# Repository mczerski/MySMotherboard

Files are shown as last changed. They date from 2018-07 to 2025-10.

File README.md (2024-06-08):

# MySMotherboard
## Motherboard for MySensors nodes

This is a motherboard for creating MySensors nodes based on the atmega328p MCU. It is meant to be combined with a MySX daughter board to create fully functional MySensors node. It is primarly for battery powered nodes but can be also used as a gateway or ac powered node (ac power supply is not part of this project). It features multiple powering options and supports RS485 or RFM69 RF communication options. The size of the board is just a little bigger than a cr123a battery holder.

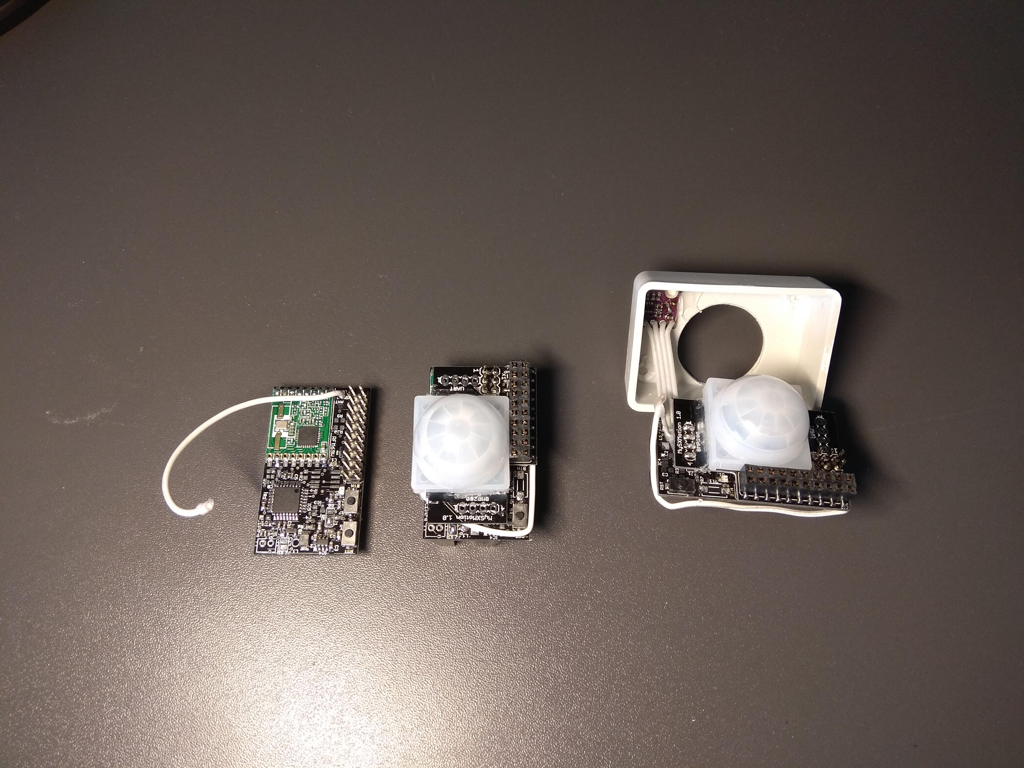
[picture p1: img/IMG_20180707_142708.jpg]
MySMotherBoard top

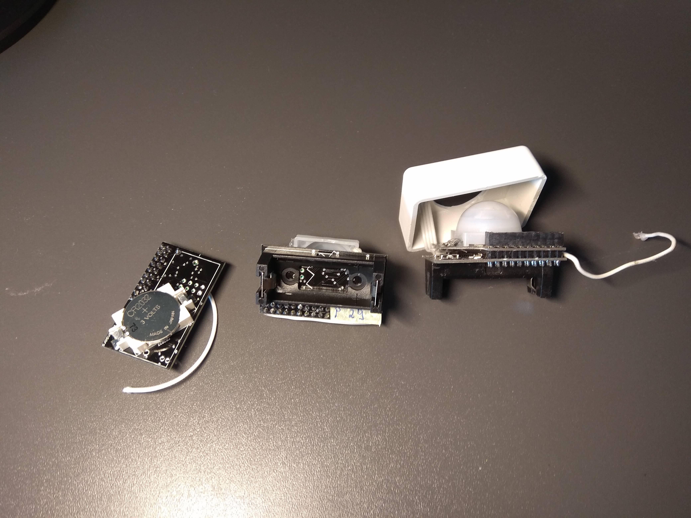
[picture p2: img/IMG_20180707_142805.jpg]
MySMotherBoard bottom


## Features:

1. atmega328p MCU
2. Multiple power source options:
  * CR123A battery or 16340 rechargable li-ion battery
  * CR2032 battery
  * JST-PH2 connector for rechargable li-ion battery
  * 24V on the 2.54mm screw terminal
  * VRAW from MySX connector
3. Multiple voltage regulator options:
  * MCP1640C boost converter with bypass option
  * TPS782 LDO linear regulator
  * AP63205WU buck converter
  * no voltage regulation - direct voltage from battery
4. Input voltage reverse polarity protection
5. Overvoltage protection for RS485 data lines
6. Battery voltage divider to monitor battery voltage
7. ATSHA204A supported
8. AT25DF512C flash suppoerted
9. RFM69 RF SMD module
10. RF module interrupt D2 pin can be disconnected if not used
11. SP3485 for RS485 communication
12. reset button
13. user button
14. user led
15. external oscillator for atmega

## HOW TO

### Minimum required parts to solder are:

1. MCU related parts:
C5, C6, C7, C10, IC5, R7
2. Radio module related parts:
C1, R1, RFM69W, antenna to ANT pad and R12 (R12 is just a 0Ohm jumper required to connect RFM69 interrupt with D2 pin)
3. RS485 interface related parts:
U8
3. MySX connector:
X2

This is bare minimum that is required to start with this board. In this configuration the board can be powered from the MySX connector VCC pin with voltage between 1.9V - 3.6V.

### Optional parts to solder are:

1. MCU related parts:
 * for user led - R8, D1
 * for reset button - RST
 * for user button connected to D2 pin - BTN
 * for I2C pull-up resistors - R9, R10
 * for external oscillator - C8, C9, Q2
2. External flash related parts:
R2, IC2
WARNING: flash chips consumes a lot of uA of current so it is not suited for battery powered nodes.
3. ATSHA204A related parts:
IC3
ATSHA204A requires at least 2.0V power supply
4. RS485 related parst (overvoltage protection on data pins):
F1, F2, D2, D3

### Powering options

The powering option is choosed in two steps. First is to select the voltage source, and second is to choose the voltage conversion type. Between the voltage source and the voltage converter ther is the reverse polarity protection mosfet Q1 which is required for all options and voltage divider for battery voltage monitoring which is not required.

Voltage source options are:
1. CR123A battery or 16340 rechargable li-ion battery. To select this option just solder CR123A battery holder.
2. CR2032 battery. To chosse this option just solder CR2032 battery holder.
3. JST-PH2 connector. To choose this option just solder the X1 connector.
4. 24V input on 2.54mm screw terminal
5. VRAW from MySX connector. To choose this option the J2 jumper must be shorted.

Reverse polarity battery protection:
Q1

Voltage divider for battery voltage monitoring:
R5, R6, C4

Voltage convertion options are:
1. MCP1640C boost converter
R3, R4, R11, C2, C3, L1, IC4, J1 jumper should connect VBOOST with VCC.
The MCP1640C boost converter can be put into bypass mode so it just passes the input voltage. It is controller by the A2 pin and the bypass mode is the default. The purpose of this functionality is to be able to run the MCU directly from the battery and to boost the voltage only for the moment required to make measurements with sensors that require higher voltages.
2. TPS782 LDO linear regulator
C13, C14, IC1. J1 jumper should connect VREG with VCC. The C12 should be replaced by the 0Ohm resistor. The C12 capacitor was designed for the APE8865 LDo which consumes much more current that TPS782.
3. AP63205WU buck converter
C1, C6, C11, U7, Q2 (for high voltage reverse polarity protection)
4. No voltage regulation
There is actually no direct way to shoose this option, but it can be done by shorting pins number 5 and 6 of the IC4 and J1 jumper should connect VBOOST with VCC.

### Powering examples.

1. Very low power temperature and humidity sensor based on the BME280 sensor.
This node uses the "No voltage conversion" option because the BME280 sensor can work with voltages as low as 1.2V. So the node may be powered just by 3V coin-cell battery. This type of node uses just CR2032 battery holder.

2. Very low power node with DS18B20 temperature sensors that require minimum 3V power supply.
This type of node uses MCP1640C boost converter to boost battery voltage for the measurement period. Use CR2032 battery holder and MCP1640C boost converter option. In the software controll properly the A2 pin to turn on/off boost conversion.

3. Motion sensor node.
Motion sensor such as AS312 consumes quite a lot of power and needs voltage between 2.7V and 3.3V. Powering it directly with 3V battery is not good, so we could use the boost converter. But boost converter makes to much noise for AS312 to work properly. The AS312 works the best with 3V LDO, so the power source should have higher voltage. The best options is to use 3.7V 16340 rechargable li-ion battery which fits into CR123A battery holder. Use TPS782 LDO option to power the MCU and RF module and short the J2 jumper to power the VRAW pin directly with 3.7V battery. Then the motion sensor daugher board should power the AS312 sensor with another LDO from the VRAW pin.

4. RS485 node.
RS485 node uses 24V input on the 2.54mm screw terminal which delivers power and RS485 communication to the board. It also utilises high voltage reverse polarity protection and overvoltage protection for data pins so any wiring mistakes will not cause damage to the board. Onboard AP63205WU buck converter provides 5V input voltage for the board which can be used directly or can be fed to the 3V LDO regulator. By soldering JP1 jumper 5V power can be connected to VRAW on the MySX connector.

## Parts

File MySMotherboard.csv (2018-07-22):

Part | Value | Package | Description
BTN |  |  | microswitch (e.g. KSR251GLFS https://www.ckswitches.com/media/1466/ksr.pdf)
RST |  |  | microswitch (e.g. KSR251GLFS https://www.ckswitches.com/media/1466/ksr.pdf)
X1 |  |  | JST-PH2 connector (http://www.jst-mfg.com/product/pdf/eng/ePH.pdf)
X2 |  |  | 10X02 PIN HEADER
C1 | 10u | C0603 | Capacitor
C2 | 4.7u | C0603 | Capacitor
C3 | 10u | C0603 | Capacitor
C4 | 100n | C0402 | Capacitor
C5 | 100n | C0402 | Capacitor
C6 | 100n | C0402 | Capacitor
C7 | 100n | C0402 | Capacitor
C8 | 22p | C0402 | Capacitor
C9 | 22p | C0402 | Capacitor
C10 | 100n | C0402 | Capacitor
C12 | 10n | C0402 | Capacitor
C13 | 10u | C0603 | Capacitor
C14 | 10u | C0603 | Capacitor
CR123A |  |  | CR123A battery holder (https://www.challengeelectronics.com/downloads/battery_accessories/lithium/BHC-CR123A.pdf)
CR2032 |  |  | CR2032 battery holder (https://www.tme.eu/pl/Document/add8937505ee3ddd8664e6e70d6b380d/DS1092-10-W6L.pdf)
D1 |  | CHIP-LED0805 | LED
IC1 | APE8865Y5-30-HF-3 | SOT25 | 150mA Low Noise LDO Voltage Regulator with Enable
IC2 | AT25DF512C-SSHN-B | SO-08 | Serial EEPROM 4K/ 8K , SPI bus
IC3 | ATSHA204A | SOT23 | CryptoAuthentication IC
IC4 | MCP1640CT-I/CHY | SOT95 | Synchronous Boost Regulator
IC5 | ATMEGA328P-AU | TQFP32 | MCU
L1 | 4.7u | L3225P | INDUCTOR, European symbol
NRF24L01 | WIRELESS-NRF24L01 |  | 2.4 GHz Wireless Module based on NRF24L01 chip
RFM69W | RFM69HW |  | RFM69W module
Q1 |  | SOT-23 | MOS FET
Q2 |  |  | 8MHz crystal oscillator
R1 | 1M | R0603 | Resistor
R2 | 1M | R0603 | Resistor
R3 | 1M | R0603 | Resistor
R4 | 620k | R0603 | Resistor
R5 | 1M | R0603 | Resistor
R6 | 100k | R0603 | Resistor
R7 | 1M | R0603 | Resistor
R8 | 1k | R0603 | Resistor
R9 | 10k | R0603 | Resistor
R10 | 10k | R0603 | Resistor
R11 | 1M | R0603 | Resistor
R12 | 0 | R0603 | Resistor

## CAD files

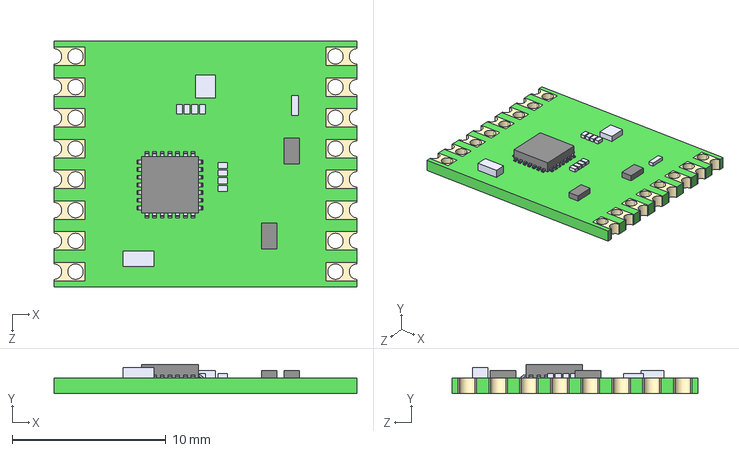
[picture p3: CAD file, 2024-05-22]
3dshapes/RFM69HW-868S2--3DModel-STEP-1.STEP
19.7 x 1.90 x 16.0 mm

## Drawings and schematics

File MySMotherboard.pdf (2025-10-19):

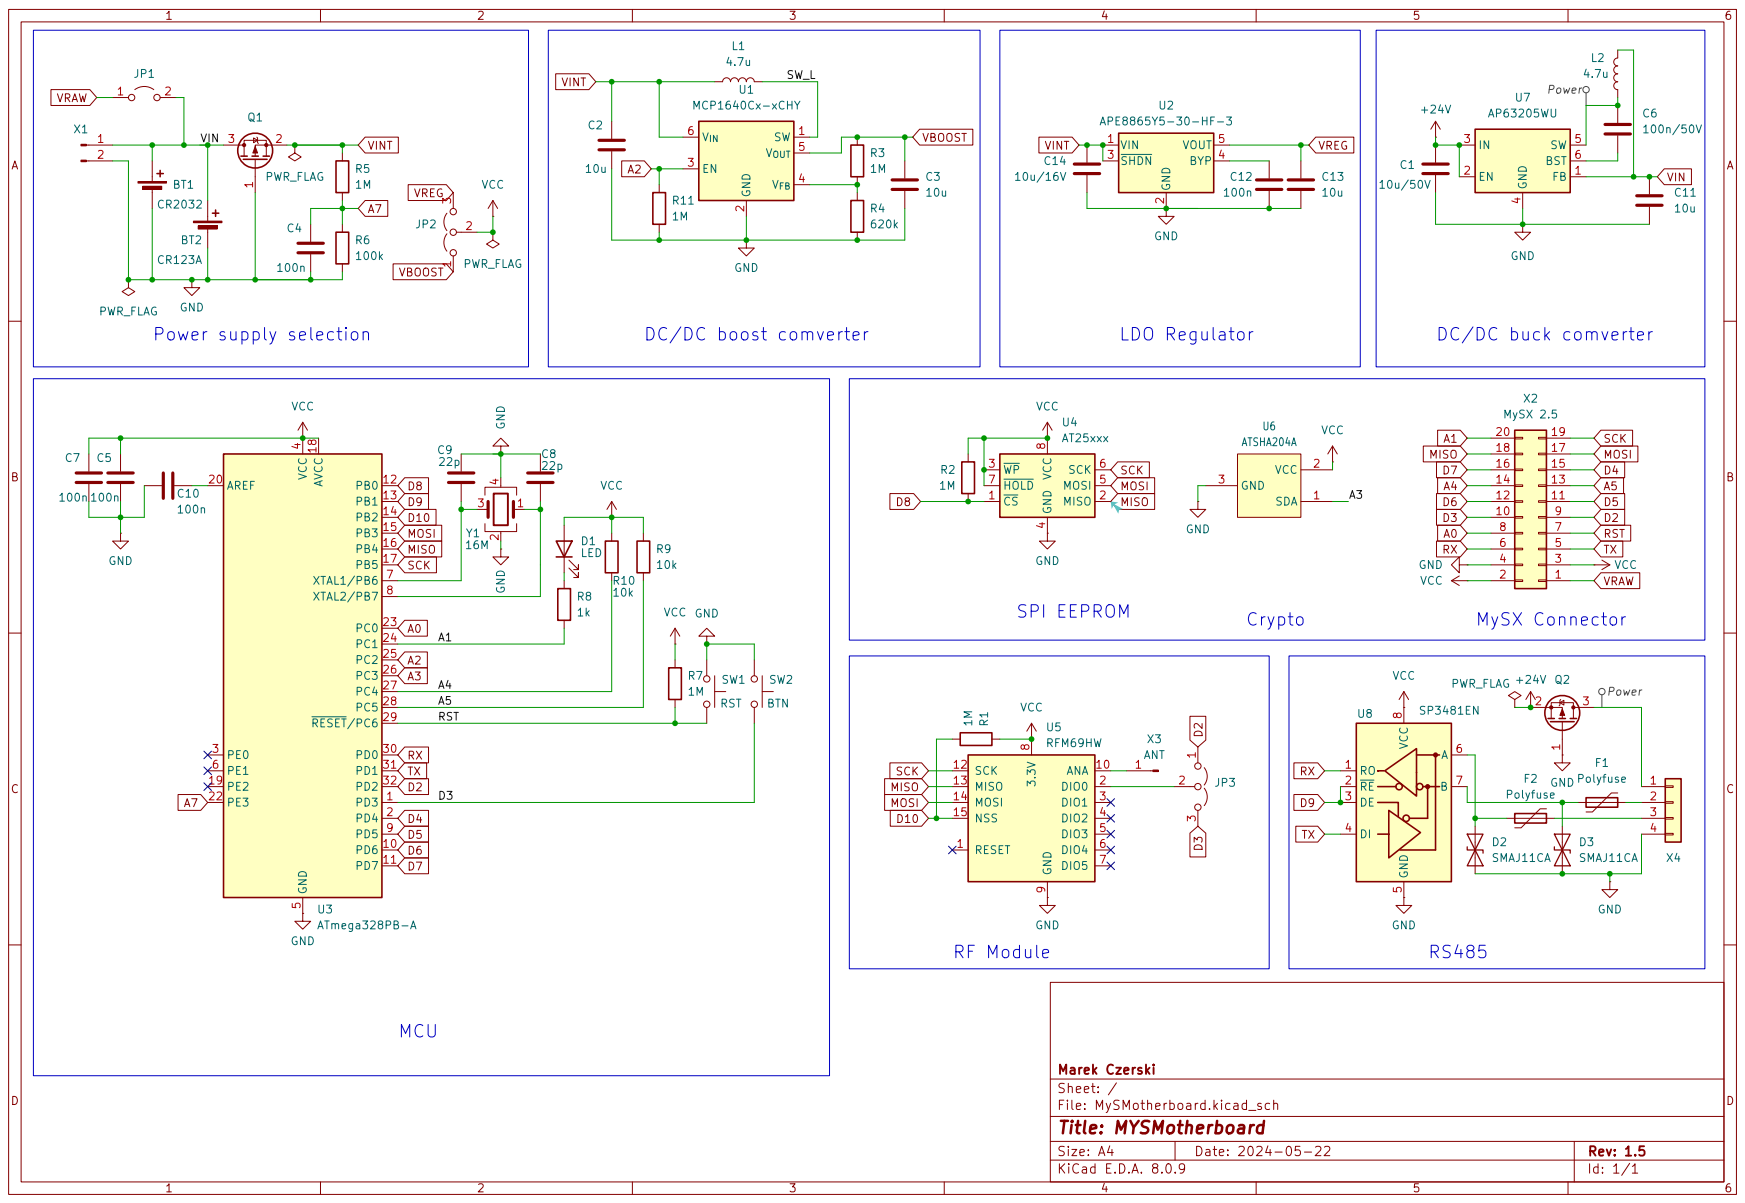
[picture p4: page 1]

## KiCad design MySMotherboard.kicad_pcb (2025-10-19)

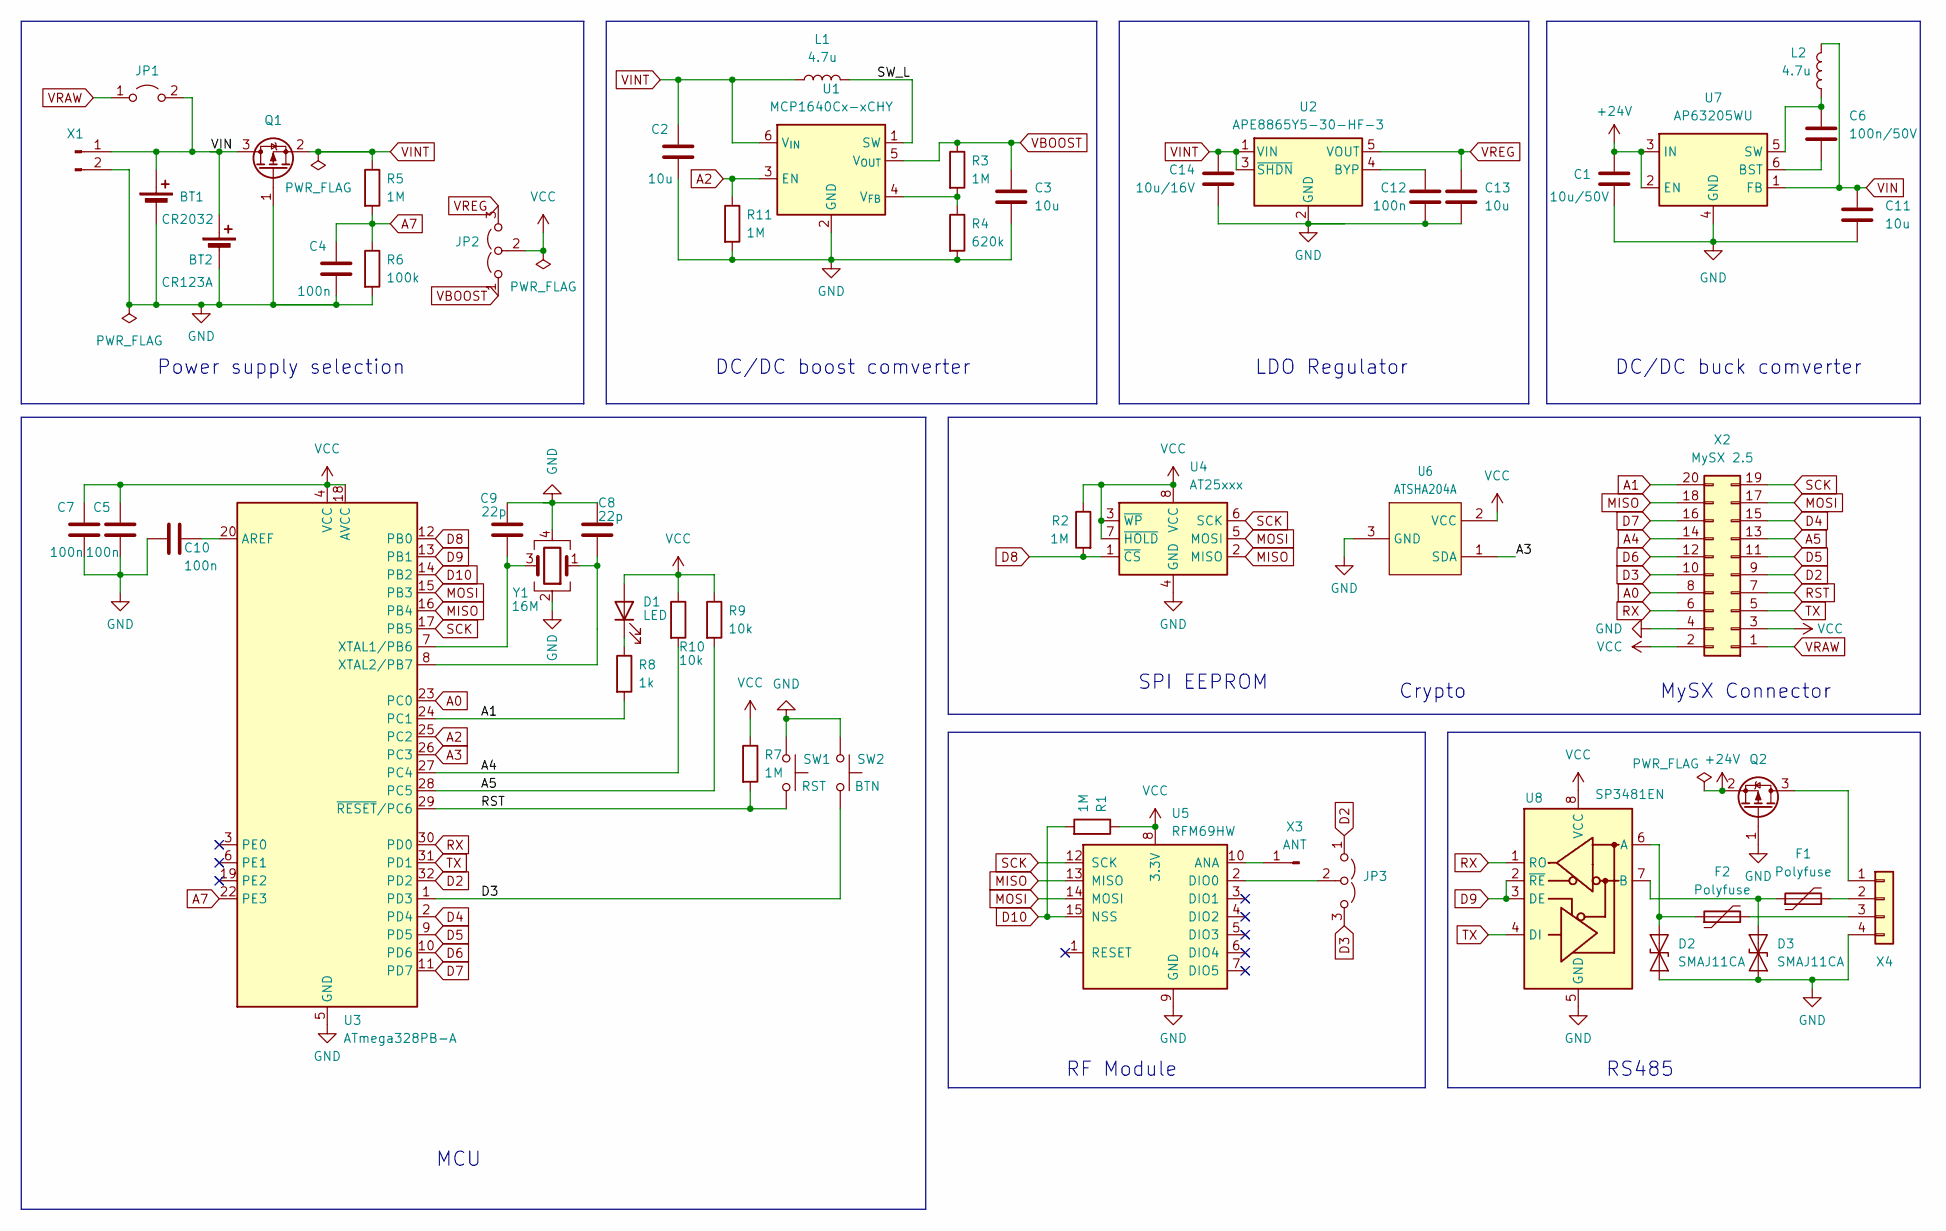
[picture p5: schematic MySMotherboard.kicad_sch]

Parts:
BT1: CR2032; BatteryHolder_Keystone_1060_1x2032
BT2: CR123A; BH123A
C1: 10u/50V; C_1206_3216Metric
C2, C3, C13: 10u; C_0603_1608Metric
C4, C5, C7, C10, C12: 100n; C_0402_1005Metric
C6: 100n/50V; C_0402_1005Metric_Pad0.74x0.62mm_HandSolder
C8, C9: 22p; C_0402_1005Metric
C11: 10u; C_1206_3216Metric
C14: 10u/16V; C_0603_1608Metric
D1: LED; LED_0805_2012Metric_Pad1.15x1.40mm_HandSolder
D2, D3: SMAJ11CA; D_SMA
F1, F2: Polyfuse; Fuse_1206_3216Metric_Pad1.42x1.75mm_HandSolder
JP1: SolderJumper-2_P1.3mm_Open_RoundedPad1.0x1.5mm
JP2, JP3: SolderJumper-3_P1.3mm_Open_RoundedPad1.0x1.5mm
L1: 4.7u; L_1210_3225Metric_Pad1.42x2.65mm_HandSolder
L2: 4.7u; L_1210_3225Metric
Q1, Q2: SOT-23
R1, R2, R3, R5, R7, R11: 1M; R_0603_1608Metric
R4: 620k; R_0603_1608Metric
R6: 100k; R_0603_1608Metric
R8: 1k; R_0603_1608Metric
R9, R10: 10k; R_0603_1608Metric
SW1: RST; SW_SPST_EVQPE1
SW2: BTN; SW_SPST_EVQPE1
U1: MCP1640Cx-xCHY; SOT-23-6
U2: APE8865Y5-30-HF-3; SOT-23-5
U3: ATmega328PB-A; TQFP-32_7x7mm_P0.8mm
U4: AT25xxx; SOIC-8_3.9x4.9mm_P1.27mm
U5: RFM69HW; HOPERF_RFM69HW
U6: ATSHA204A; SOT-23
U7: AP63205WU; TSOT-23-6
U8: SP3481EN; SOIC-8_3.9x4.9mm_P1.27mm
X1: JST_PH_B2B-PH-K_1x02_P2.00mm_Vertical
X2: MySX 2.5; PinHeader_2x10_P2.54mm_Vertical
X3: ANT; PinHeader_1x01_P2.54mm_Vertical
X4: TerminalBlock_Phoenix_MPT-0,5-4-2.54_1x04_P2.54mm_Horizontal
Y1: 16M; Crystal_SMD_2520-4Pin_2.5x2.0mm

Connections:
+24V: C1.1, Q2.2 (S), U7.2 (EN), U7.3 (IN)
/SW_L: L1.2, U1.1 (SW)
A0: U3.23 (PC0), X2.8
A1: R8.2, U3.24 (PC1), X2.20
A2: R11.1, U1.3 (EN), U3.25 (PC2)
A3: U3.26 (PC3), U6.1 (SDA)
A4: R10.2, U3.27 (PC4), X2.14
A5: R9.2, U3.28 (PC5), X2.13
A7: C4.1, R5.2, R6.1, U3.22 (PE3)
D2: JP3.1 (A), U3.32 (PD2), X2.9
D3: JP3.3 (B), SW2.1, U3.1 (PD3), X2.10
D4: U3.2 (PD4), X2.15
D5: U3.9 (PD5), X2.11
D6: U3.10 (PD6), X2.12
D7: U3.11 (PD7), X2.16
D8: R2.2, U3.12 (PB0), U4.1 (~CS)
D9: U3.13 (PB1), U8.2 (~RE), U8.3 (DE)
D10: R1.2, U3.14 (PB2), U5.15 (NSS)
GND: BT1.2 (-), BT2.2 (-), C1.2, C2.2, C3.2, C4.2, C5.2, C7.2, C8.1, C9.2, C10.2, C11.2, C12.2, C13.2, C14.2, D2.1 (A1), D3.1 (A1), Q1.1 (G), Q2.1 (G), R4.2, R6.2, R11.2, SW1.2, SW2.2, U1.2 (GND), U2.2 (GND), U3.5 (GND), U3.21 (GND), U4.4 (GND), U5.9 (GND), U5.11 (GND), U6.3 (GND), U7.4 (GND), U8.5 (GND), X1.2, X2.4, X4.4, Y1.2, Y1.4
MISO: U3.16 (PB4), U4.2 (MISO), U5.13 (MISO), X2.18
MOSI: U3.15 (PB3), U4.5 (MOSI), U5.14 (MOSI), X2.17
unnamed: D1.1 (K), R8.1
unnamed: D2.2 (A2), F2.1, U8.6 (A)
unnamed: D3.2 (A2), F1.1, U8.7 (B)
unnamed: JP3.2 (C), U5.2 (DIO0)
unnamed: Q2.3 (D), X4.1
unnamed: R3.2, R4.1, U1.4 (V_{FB})
unnamed: C12.1, U2.4 (BYP)
unnamed: C10.1, U3.20 (AREF)
unnamed: C9.1, U3.7 (XTAL1/PB6), Y1.3
unnamed: C8.2, U3.8 (XTAL2/PB7), Y1.1
unnamed: U5.10 (ANA), X3.1
unnamed: C6.1, U7.6 (BST)
unnamed: C6.2, L2.1, U7.5 (SW)
unnamed: F1.2, X4.2
unnamed: F2.2, X4.3
RST: R7.2, SW1.1, U3.29 (~RESET/PC6), X2.7
RX: U3.30 (PD0), U8.1 (RO), X2.6
SCK: U3.17 (PB5), U4.6 (SCK), U5.12 (SCK), X2.19
TX: U3.31 (PD1), U8.4 (DI), X2.5
VBOOST: C3.1, JP2.1 (A), R3.1, U1.5 (V_{OUT})
VCC: C5.1, C7.1, D1.2 (A), JP2.2 (C), R1.1, R2.1, R7.1, R9.1, R10.1, U3.4 (VCC), U3.18 (AVCC), U4.3 (~WP), U4.7 (~HOLD), U4.8 (VCC), U5.8 (3.3V), U6.2 (VCC), U8.8 (VCC), X2.2, X2.3
VIN: BT1.1 (+), BT2.1 (+), C11.1, JP1.2 (B), L2.2, Q1.3 (D), U7.1 (FB), X1.1
VINT: C2.1, C14.1, L1.1, Q1.2 (S), R5.1, U1.6 (V_{IN}), U2.1 (VIN), U2.3 (~SHDN)
VRAW: JP1.1 (A), X2.1
VREG: C13.1, JP2.3 (B), U2.5 (VOUT)

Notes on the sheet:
RS485
LDO Regulator
DC/DC boost comverter
RF Module
Crypto
MySX Connector
MCU
SPI EEPROM
DC/DC buck comverter
Power supply selection

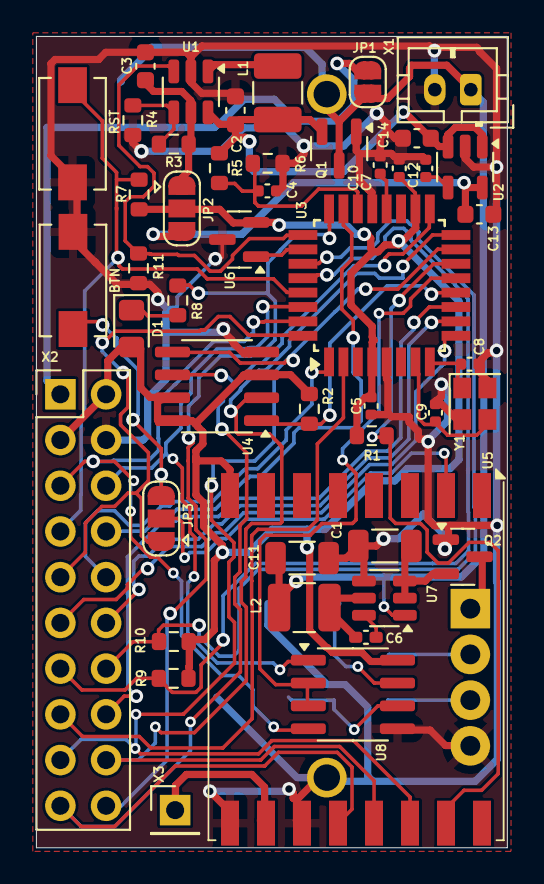
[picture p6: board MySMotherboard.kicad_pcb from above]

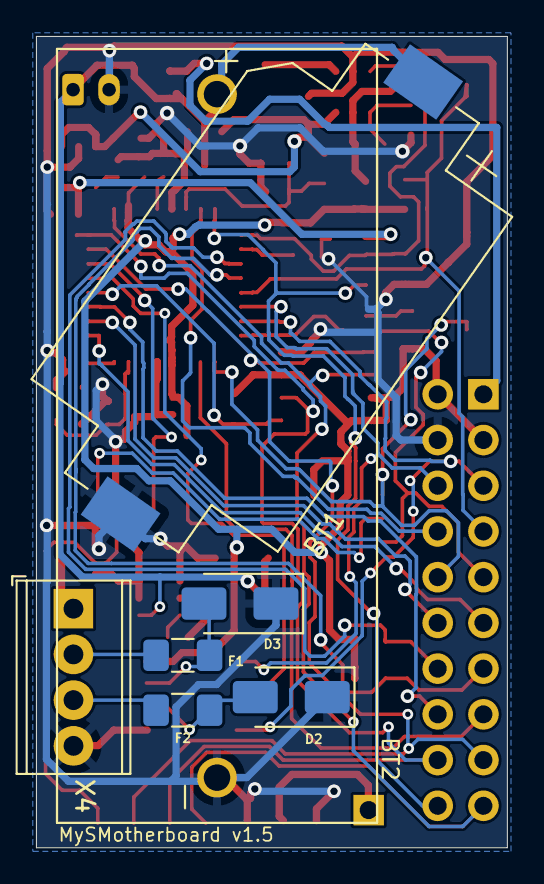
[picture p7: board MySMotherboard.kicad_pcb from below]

Board: 2 copper layers, 26.2 x 45.1 mm, 54 parts (7 on the bottom side), 46 nets.

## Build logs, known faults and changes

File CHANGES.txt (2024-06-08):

Modifications made by Licensee (see section 3.4.b in the LICENSE.txt file)

v1.4 - Remove NRF24L01, add RS485 instead. Also support 24V power input with step down DC/DC converter.
v1.3 - First public release

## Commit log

2017-10-14 initial commit - raw version, just schematic and pcb layout
    [MysensorsSensor.brd, MysensorsSensor.sch]
2017-12-07 1. fix wrong boost converter footprint 2. connect led to A1 pin instead of A2 (which was used by the boost converter enable 3. change crystal footrint but not change the pcb
    [MysensorsSensor.brd, MysensorsSensor.sch]
2017-12-07 1. rearrange nfr24l01 connector and atmega328p chip
    [MysensorsSensor.brd, MysensorsSensor.sch]
2018-02-08 connect radio module irq with d2
    [MysensorsSensor.brd, MysensorsSensor.sch]
2018-05-15 use p-mosfet for reverse polarity
    [MysensorsSensor.brd, MysensorsSensor.sch]
2018-05-17 add RFM69
    [MysensorsSensor.brd, MysensorsSensor.sch]
2018-06-10 add 0Ohm resistor for radio module interrupt + connect button to D3
    [MysensorsSensor.brd, MysensorsSensor.sch]
2018-06-10 move ldo to top layer
    [MysensorsSensor.brd]
2018-06-10 rotate cr2032 battery pack to about 55 degrees
    [MysensorsSensor.brd]
2018-07-22 rename files
    [MySMotherboard.brd, MySMotherboard.sch]
2018-07-22 add documentation files
    [MySMotherboard.GBL, MySMotherboard.GBO, MySMotherboard.GBS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]
2018-07-23 add license documentation
    [MySMotherboard.brd]
2018-07-23 update gerbers after adding license notice
    [MySMotherboard.GBO]
2024-05-20 convert to KiCad
    [MySMotherboard.brd, MySMotherboard.kicad_pcb, MySMotherboard.kicad_sch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]
2024-05-22 refactor schematic to use native KiCad symbols and footprints
    [MySMotherboard.kicad_pcb, MySMotherboard.kicad_sch, RFM69HW-868S2--3DModel-STEP-1.STEP]
2024-05-25 replace NRF24L01 with RS485 inteface
    [MySMotherboard.kicad_pcb, MySMotherboard.kicad_sch]
2024-06-07 change bypass capacitor for buck dc/dc converter to 50V 0603
    [MySMotherboard.kicad_sch]
2024-06-07 add protection circuitry for RS485 IC AB lines
    [MySMotherboard.kicad_sch]
2024-06-07 add reverse polarity protection for 24V input
    [MySMotherboard.kicad_sch]
2024-06-08 update PCB with latest changes
    [MySMotherboard.kicad_pcb, MySMotherboard.kicad_sch]
2024-06-08 update gerber files
    [MySMotherboard-B_Cu.gbl, MySMotherboard-B_Mask.gbs, MySMotherboard-B_Paste.gbp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]
2024-06-08 update README and schematic pdf export
2024-06-08 change 22uF cap on buck converter output to 10uF
    10uF should be sufficient
    [MySMotherboard.kicad_sch]
2024-06-08 change bypass capacitor for buck converter from 0603 to 0402
    [MySMotherboard.kicad_pcb, MySMotherboard.kicad_sch]
2024-07-24 update parts documentation sources
    [MySMotherboard.kicad_sch]
2025-01-03 update to kicad 8
    [MySMotherboard.kicad_pcb, MySMotherboard.kicad_sch]
2025-10-19 add pull-up resistor for RFM69W NSS pin
    [MySMotherboard.kicad_pcb, MySMotherboard.kicad_sch]
2025-10-19 add option to connect RFM69W irq to pin 3
    [MySMotherboard.kicad_pcb, MySMotherboard.kicad_sch]
2025-10-19 update production files
    [MySMotherboard-B_Cu.gbl, MySMotherboard-B_Mask.gbs, MySMotherboard-B_Paste.gbp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]
